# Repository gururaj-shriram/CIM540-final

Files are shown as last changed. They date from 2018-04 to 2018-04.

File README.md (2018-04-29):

# CIM540 Final Project: Word Jam
### A tetris-like, story making game… with a laser!

Word Jam is a game that lets the player create stories from randomly generated words. Players can add random words, delete random words, and move words from one position to another in order to try to create a story. Word Jam is best played as a projection on a screen with its physical controller, which uses a joystick that controls a laser to move around the screen; it can also be played on a computer screen using the mouse and keyboard as a controller. 

### Authors 

* Gururaj Shriram (physical computing)
* Jerry Bonnell (front-end)

## Instructions

### With the Arduino Controller

Note: To use the Arduino Controller, the Node framework must be used which can be downloaded using [these instructions](https://nodejs.org/en/download/).

First, project the game's canvas onto a larger physical surface or a screen. If necessary, change the pins in `Word_Jam.ino`, the Arduino serial port in `sketch.js`, and/or the flag `IS_USING_ARDUINO_CONTROLLER` in `sketch.js` to reflect the setup. 

To begin Word Jam, connect the Arduino to the computer, upload `Word_Jam.ino`, and run:

```shell
$ npm install
$ npm start
```

Next, open `index.html` in a browser. Opening this file should not be done on the server side (e.g. `localhost:PORT/index.html`) due to the usage of the p5 Serial library. Instead, it should be directly opened with its relative path (e.g. `file://WordJam/index.html`). 

Because p5 Serial is used in tandem with the p5 Sound library, which requires a local server to be used, the current program may not work on `Google Chrome` because its browser security features do not allow loading assets from a file path. The current workaround is using `Mozilla Firefox`.

To summarize running the server: 
* Run the local server with the aforementioned commands
* Open `index.html` with its relative path instead of on the local server 
* Use `Mozilla Firefox` or another browser which allows loading assets from a file path

If everything works well, a cursor ('X') should appear on screen.

#### Controls
* Joystick to move the laser and on screen cursor
* Joystick click on a word to grab and release it (to change its position)
* Green button to add a random word
* Red button to delete the word that is currently being grabbed by the cursor

#### Calibration
Before we're ready to roll, the controller should be calibrated to the dimensions of the surface or screen where Word Jam is being played. Calibration is simple and has the following steps:

1. Move the laser/cursor to the top left of the canvas
2. Repeatedly press the `s` key on the keyboard until the cursor changes position to the top left of the canvas
3. Move the laser/cursor to the bottom right of the canvas
4. Repeatedly press the `e` key on the keyboard until the cursor changes position to the bottom right of the canvas

And now, everything's all set to start Word Jamming!

### Without the Arduino Controller

To begin, change the Arduino enabled flag, `IS_USING_ARDUINO_CONTROLLER`, in `sketch.js` to `false` and open `index.html` either in a browser that supports loading assets from a file path, such as `Mozilla Firefox`, or run a local server and open `index.html` on the server side using any browser (see the above instructions which have details on running the server).

#### Controls
* Mouse to move
* Mouse click on a word to grab and release it (to change its position)
* (P)ush a new random word
* (R)emove the word that is currently being grabbed by the cursor

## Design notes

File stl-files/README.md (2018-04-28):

# STL Files

## Laser Pointer Clamp
This file contains the clamp used to place the laser pointer on top of the Pan/Tilt Device.

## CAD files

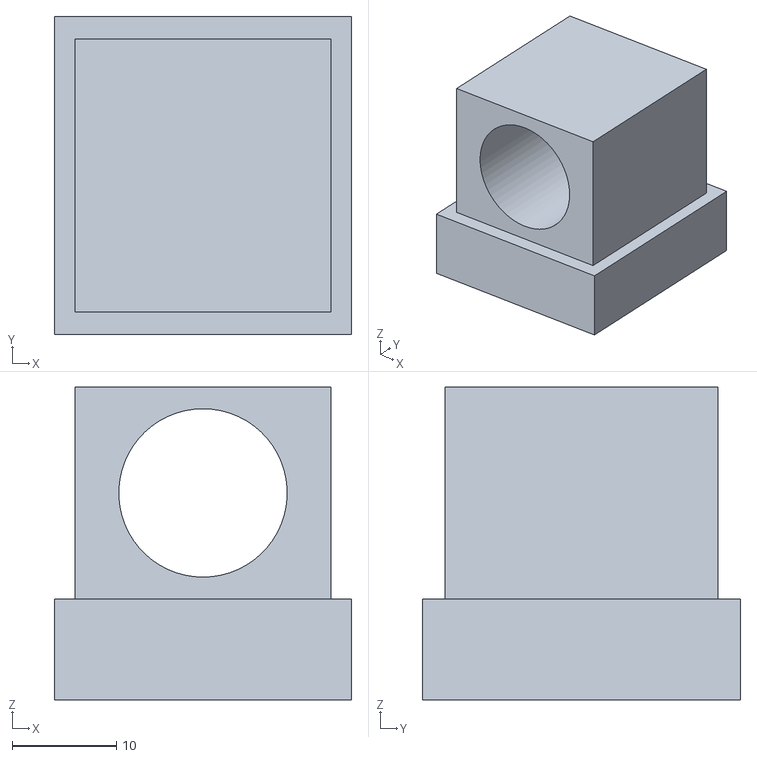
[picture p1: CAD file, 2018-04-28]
stl-files/Laser Pointer Clamp.stl
28.5 x 30.5 x 30.0

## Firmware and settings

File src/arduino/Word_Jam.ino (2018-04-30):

#include<Servo.h>

// The joystick on the controller is rotated 90 degrees counterclockwise
// from where it should be. Hence, "X" corresponds to the "Y" direction
// and vice-a-versa. The "Y" on the joystick ("X" for the controller) is flipped, 
// so that 0 is actually 1023 and vice-a-versa. The "X" on the joystick ("Y" for the 
// controller) is flipped for practical purposes since the pan and tilt device is
// inverted to allow the laser to move higher

// Changeable pins
const int joystickYPin = A0; 
const int joystickXPin = A1;
const int joystickClickPin = 2; 
const int tiltPin = 3;
const int panPin = 4;
const int addButtonPin = 6;
const int removeButtonPin = 5;

const int minPanValue = 600;
const int maxPanValue = 2300;
const int minTiltValue = 900;
const int maxTiltValue = 2300;
const int minServoOffset = -3;
const int maxServoOffset = 3;
const int doSomethingVal = 1;
const int doNothingVal = 0;

// Temp variables to receive raw input and calc offsets
int servoVal = 0;
int joystickVal = 0;
int buttonState;
int temp = 0;

// Hashed Values
int prevPanVal = 1500;
int prevTiltVal = minTiltValue;
int prevAddButtonState = 0;
int prevRemoveButtonState = 0;
int prevjoystickButtonState = 0;

Servo pan;
Servo tilt;

void setup() {
  pan.attach(panPin);
  tilt.attach(tiltPin);

  pinMode(joystickClickPin, INPUT_PULLUP);
  pinMode(addButtonPin, INPUT_PULLUP);
  pinMode(removeButtonPin, INPUT_PULLUP);
  
  Serial.begin(9600);
}

void loop() {

  // Move pan
  joystickVal = analogRead(joystickXPin);
  temp = map(joystickVal, 0, 1023, minServoOffset, maxServoOffset);

  // To decrease sensitivity
  if (temp >= -1 && temp <= 1) {
    temp = 0;
  }
  
  // Add/Subtract a small offset so that the movements are relatively smooth
  servoVal = prevPanVal + temp;
  servoVal = constrain(servoVal, minPanValue, maxPanValue); // in case it's over the threshold
  prevPanVal = servoVal;
  
  // Write pan val first
  // It is flipped for the p5 canvas
  Serial.print(maxPanValue - servoVal);
  Serial.print(" ");
  pan.writeMicroseconds(servoVal);

  // Move tilt
  joystickVal = analogRead(joystickYPin);  
  temp = map(joystickVal, 0, 1023, minServoOffset, maxServoOffset);

  // To decrease sensitivity
  if (temp >= -1 && temp <= 1) {
    temp = 0;
  }

  // Add/Subtract a small offset so that the movements are relatively smooth
  servoVal = prevTiltVal + temp;
  servoVal = constrain(servoVal, minTiltValue, maxTiltValue); // in case it's over the threshold
  prevTiltVal = servoVal;
  
  // Write tilt val second
  // It is flipped for the p5 canvas
  Serial.print(maxTiltValue - servoVal);
  Serial.print(" ");
  tilt.writeMicroseconds(servoVal);

  buttonState = digitalRead(addButtonPin);

  if (buttonState != prevAddButtonState) {
    prevAddButtonState = buttonState;
    
    // Write add button state third
    // 0 is on in INPUT_PULLUP
    if (buttonState == 0) {
      Serial.print(doSomethingVal);
      Serial.print(" ");
    } else {
      Serial.print(doNothingVal);
      Serial.print(" ");
    }
  } else {
    Serial.print(doNothingVal);
    Serial.print(" ");
  }

  buttonState = digitalRead(removeButtonPin);

  if (buttonState != prevRemoveButtonState) {
    prevRemoveButtonState = buttonState;
    
    // Write remove button state fourth
    // 0 is on in INPUT_PULLUP
    if (buttonState == 0) {
      Serial.print(doSomethingVal);
      Serial.print(" ");
    } else {
      Serial.print(doNothingVal);
      Serial.print(" ");
    }
  } else {
    Serial.print(doNothingVal);
    Serial.print(" ");
  }
  
  buttonState = digitalRead(joystickClickPin);

  if (buttonState != prevjoystickButtonState) {
    prevjoystickButtonState = buttonState;
    
    // Write joystick button state fifth
    // 0 is on in INPUT_PULLUP
    if (buttonState == 0) {
      Serial.print(doSomethingVal);
      Serial.println();
    } else {
      Serial.print(doNothingVal);
      Serial.println();
    }
  } else {
    Serial.print(doNothingVal);
    Serial.println();
  }
}

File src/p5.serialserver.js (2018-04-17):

/*
	p5.serialserver.js
*/
var SerialPort = require("serialport");

var LOGGING = false;

var wss = null;
var serialPort = null;
var serialPortName = "";
var clients = [];

var logit = function(mess) {
	if (LOGGING) {
		console.log(mess);
	}
};

var start = function () { 
	logit("start()");

	var SERVER_PORT = 8081;

	var WebSocketServer = require('ws').Server;
	wss = new WebSocketServer({perMessageDeflate: false, port: SERVER_PORT});

	var openSerial = function(serialport, serialoptions) {
		logit("openSerial: " + serialport);

		if (serialPort == null || serialPort.isOpen() == false) {
			logit("serialPort == null || !serialPort.isOpen()");

			serialPortName = serialport;

			if (!serialoptions.hasOwnProperty('autoOpen')) {
				serialoptions.autoOpen = false;
			}

			serialPort = new SerialPort(serialport, serialoptions, 
				function(err) {
					if (err) {
						console.log(err);
						sendit({method:'error', data: err});
					}
				}
			);

			serialPort.on('data', function(incoming) {
				//{"type":"Buffer","data":[10]}
				for (var i = 0; i < incoming.length; i++) {
					sendit({method:'data',data:incoming[i]});	
				}
			});

			serialPort.on('close', function(data) {
				logit("serialPort.on close");
				sendit({method: 'close', data:data});
			});

			serialPort.on('error', function(data) {
				logit("serialPort.on error " + data, true);
				sendit({method: 'error', data:data});
			});				

			serialPort.open(function (err) {
				logit("serialPort.open");

				if ( err ) {
					console.log(err);
					sendit({method:'error', data:"Couldn't open port: " + serialport});
				} else {
					sendit({method:'openserial',data:{}});
				}
		    });

		} else {

			if (serialport == serialPortName) {

				sendit({method:'error', data:"Already open"});
				logit("serialPort is already open");
				sendit({method:'openserial',data:{}});

			} else {

				// Trying to open a second port
				sendit({method:'error', data:"Unsupported operation, "+serialPortName+" is already open. You will receive data from that port."});
				logit("Unsupported operation, "+serialPortName+" is already open.");
			}
		}
	};

	var closeSerial = function() {
		logit("closeSerial");
		if (serialPort != null && serialPort.isOpen()) {
			logit("serialPort != null && serialPort.isOpen so close");
			logit("serialPort.flush, drain, close");

			serialPort.flush();
			serialPort.drain();
			serialPort.close(
				function(error) {
					if (error) {
						sendit({method:'error', data:error});
						console.log(error);
					}
				}
			);
			serialPort = null;
		}

		// Let's try to close a different way
		if (serialPort != null && serialPort.isOpen()) {
			logit("serialPort != null && serialPort.isOpen() is true so serialPort = null");

			serialPort = null;
		}

	};


	var sendit = function(toSend) {
		var dataToSend = JSON.stringify(toSend);
		for (var c = 0; c < clients.length; c++) {
			try {
				clients[c].send(dataToSend);
			} catch (error) {
				console.log("Error sending: ", error);
			}
		}
	};

	wss.on("connection", (ws) => {
		// Push the connection into the array of clients
		clients.push(ws);
		// Create an object to hold information about the connection
		ws.clientData = {
			origin: ws.upgradeReq.headers['origin'],
			id: ws.upgradeReq.headers['sec-websocket-key']
		}
		sendit({method: 'registerClient', data: ws.clientData})
	
		SerialPort.list(function (err, ports) {
			var portNames = [];
			ports.forEach(function(port) {
				portNames.push(port.comName);
			});
			sendit({method: 'list', data: portNames});
		});

		ws.on('message', function(inmessage) {
			var message = JSON.parse(inmessage);

			if (typeof message !== "undefined" && typeof message.method !== "undefined" && typeof message.data !== "undefined") {
					if (message.method === "echo") {
						sendit({method:'echo', data:message.data});
					} else if (message.method === "registerClient") {
						for (var c = 0; c < clients.length; c++) {
							sendit({method: 'registerClient', data: clients[c].clientData})
						}
					} else if (message.method === "list") {
						SerialPort.list(function (err, ports) {
							var portNames = [];
							ports.forEach(function(port) {
								portNames.push(port.comName);
							});

							sendit({method:'list', data:portNames});
						});
					} else if (message.method === "openserial") {	

						logit("message.method === openserial");
							
						// Open up
						if (typeof message.data.serialport === 'string') {
							logit("new SerialPort.SerialPort");

							openSerial(message.data.serialport, message.data.serialoptions);

						} else {
							logit("User didn't specify a port to open");
							sendit({method: 'error', data:"You must specify a serial port to open"});
						}

					} else if (message.method === "write") {
						
						serialPort.write(message.data);

					} else if (message.method === "close") {
						logit("message.method === close");
						closeSerial();
					}
			}
			else {
				console.log("Not a message I understand: " + JSON.stringify(message));
			}
		});

		ws.on('close', function() {
			logit("ws.on close - client left");

			for (var c = 0; c < clients.length; c++) {
				if (clients[c] === ws) {
					logit("removing client from array");

					clients.splice(c,1);

					logit(clients.length + " clients left");
					break;
				}
			}

			if (clients.length == 0) {
				logit("clients.length == 0 checking to see if we should close serial port")
				// Should close serial port
				closeSerial();
			}
		});
	});
};

var stop = function() {
	logit("stop()");

	if (serialPort != null && serialPort.isOpen()) {
		logit("serialPort != null && serialPort.isOpen() is true");
		logit("serialPort.flush, drain, close");

		serialPort.flush();
		serialPort.drain();
		serialPort.close(
			function(error) {
				if (error) {
					console.log("Close Error: " + error);
				}
			}
		);
	}		

	try {
		for (var c = 0; c < clients.length; c++) {
			if (clients[c] != null) {
				logit("clients[" + c + "] != null, close");

				clients[c].close();
			}
		}
	} catch (e) {
		console.log("Error Closing: " + e);
	}

	if (wss != null) {
		logit("wss != null so wss.close()");
		wss.close();
	}
	
	// Let's try to close a different way
	if (serialPort != null && serialPort.isOpen()) {
		logit("serialPort != null && serialPort.isOpen() is true so serialPort = null");
		serialPort = null;
	}
}

module.exports.start = start;
module.exports.stop = stop;

//start();

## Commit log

2018-04-16 add untested arduino code as a starter
2018-04-16 add working calibration
2018-04-17 p5 serial requires some node modules. modify sketch temporarily to use a flag to control whether an arduino controller is used.
2018-04-18 arduino code almost done
2018-04-24 add some soundz. for reasons, the arduino and sound together won't work on Chrome ¯\_(ツ)_/¯
2018-04-27 add keyboard calibration
2018-04-28 add laser pointer clamp stl
    [Laser Pointer Clamp.stl]
